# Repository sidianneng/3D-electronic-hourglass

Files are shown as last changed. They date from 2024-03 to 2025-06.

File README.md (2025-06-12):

# 3D 电子沙漏 | [3D Electronic hourglass](./README-EN.md)
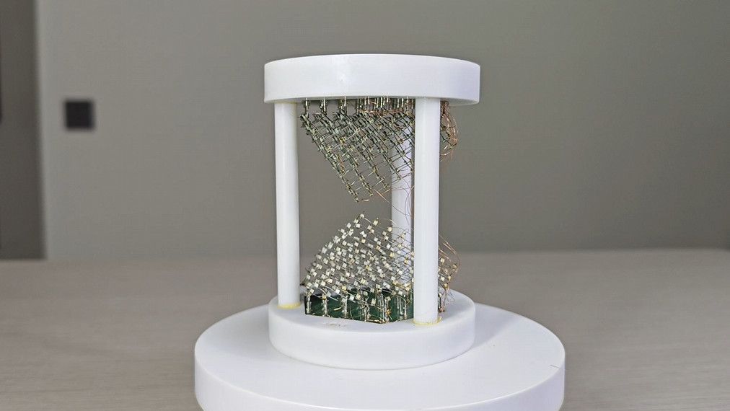
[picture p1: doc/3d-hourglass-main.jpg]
3D Electronic hourglass


## 1 项目概述
本项目是常见的平面电子沙漏的改进版本，在其基础上添加了3D显示结构，匹配对应的显示控制效果，实现了3D立体显示的电子沙漏功能。

## 2 功能介绍
* 开机后随机开始模拟沙漏运行的效果
* 通过陀螺以判断沙漏姿态，来实现不同的运行效果
* 上下各有一个按键，按下后可以切换不同的计时时间(todo)
* 上下各有三个指示灯，用来显示当下正在计时的时间(todo)
* 支持电池供电和充电

## 3 原理解析
* 本项目通过对传统888光立方的创新改装实现
* 通过旋转和剪切立方体，得到与沙漏相似的外观结构
* 通过与平面电子沙漏类似的控制方法实现沙子的流动效果 

### 如果对本项目有任何疑问，欢迎在issue中与我讨论。

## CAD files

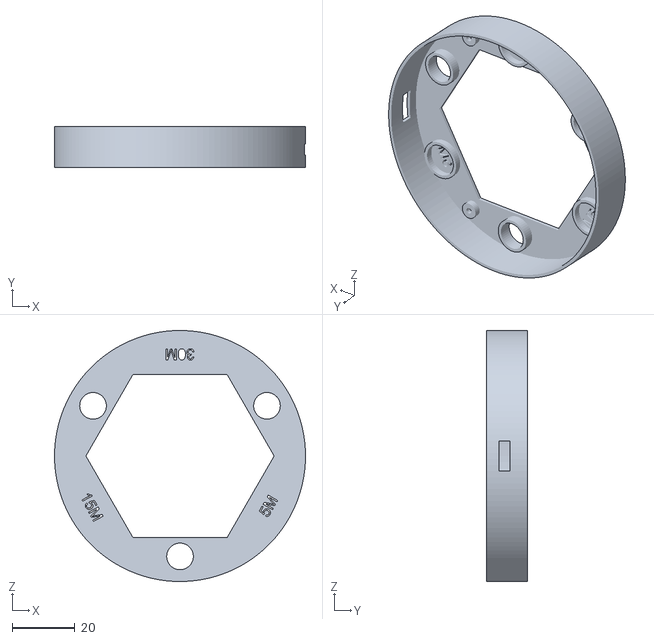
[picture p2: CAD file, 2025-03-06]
3d-modules/bottom-main-v2.stl
80.0 x 13.0 x 80.0

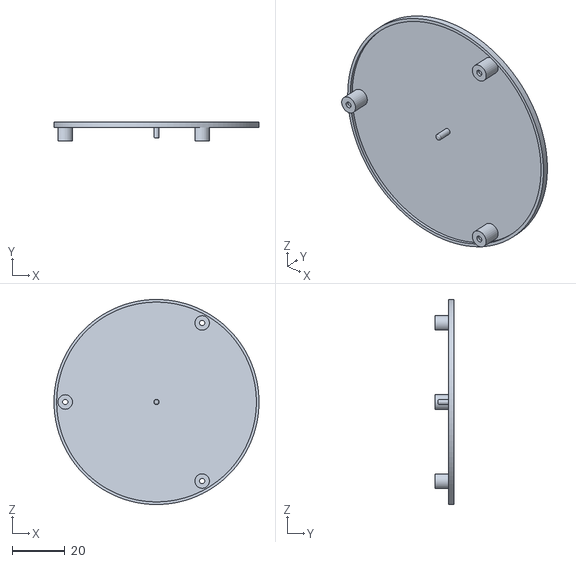
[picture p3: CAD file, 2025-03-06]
3d-modules/bottom-main2-v7.stl
77.5 x 7.00 x 77.5

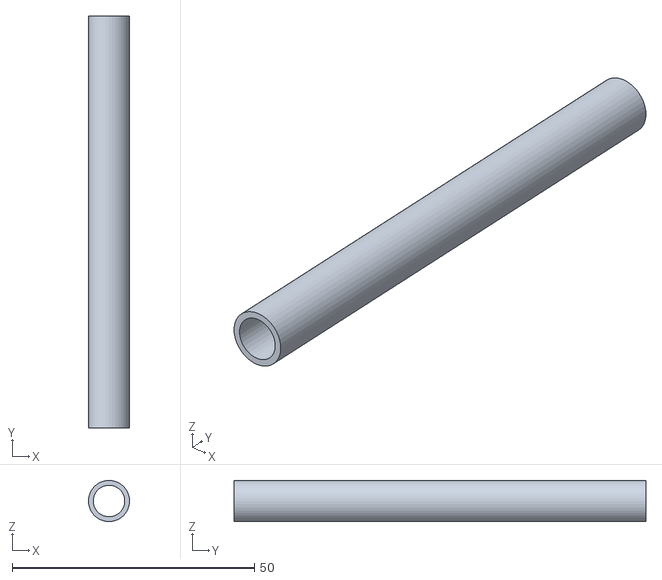
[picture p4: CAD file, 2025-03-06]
3d-modules/hourglass-pillar-v3.stl
8.50 x 85.0 x 8.50

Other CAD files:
3d-modules/top-main-v2.stl

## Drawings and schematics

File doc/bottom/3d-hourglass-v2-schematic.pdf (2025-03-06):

5

4

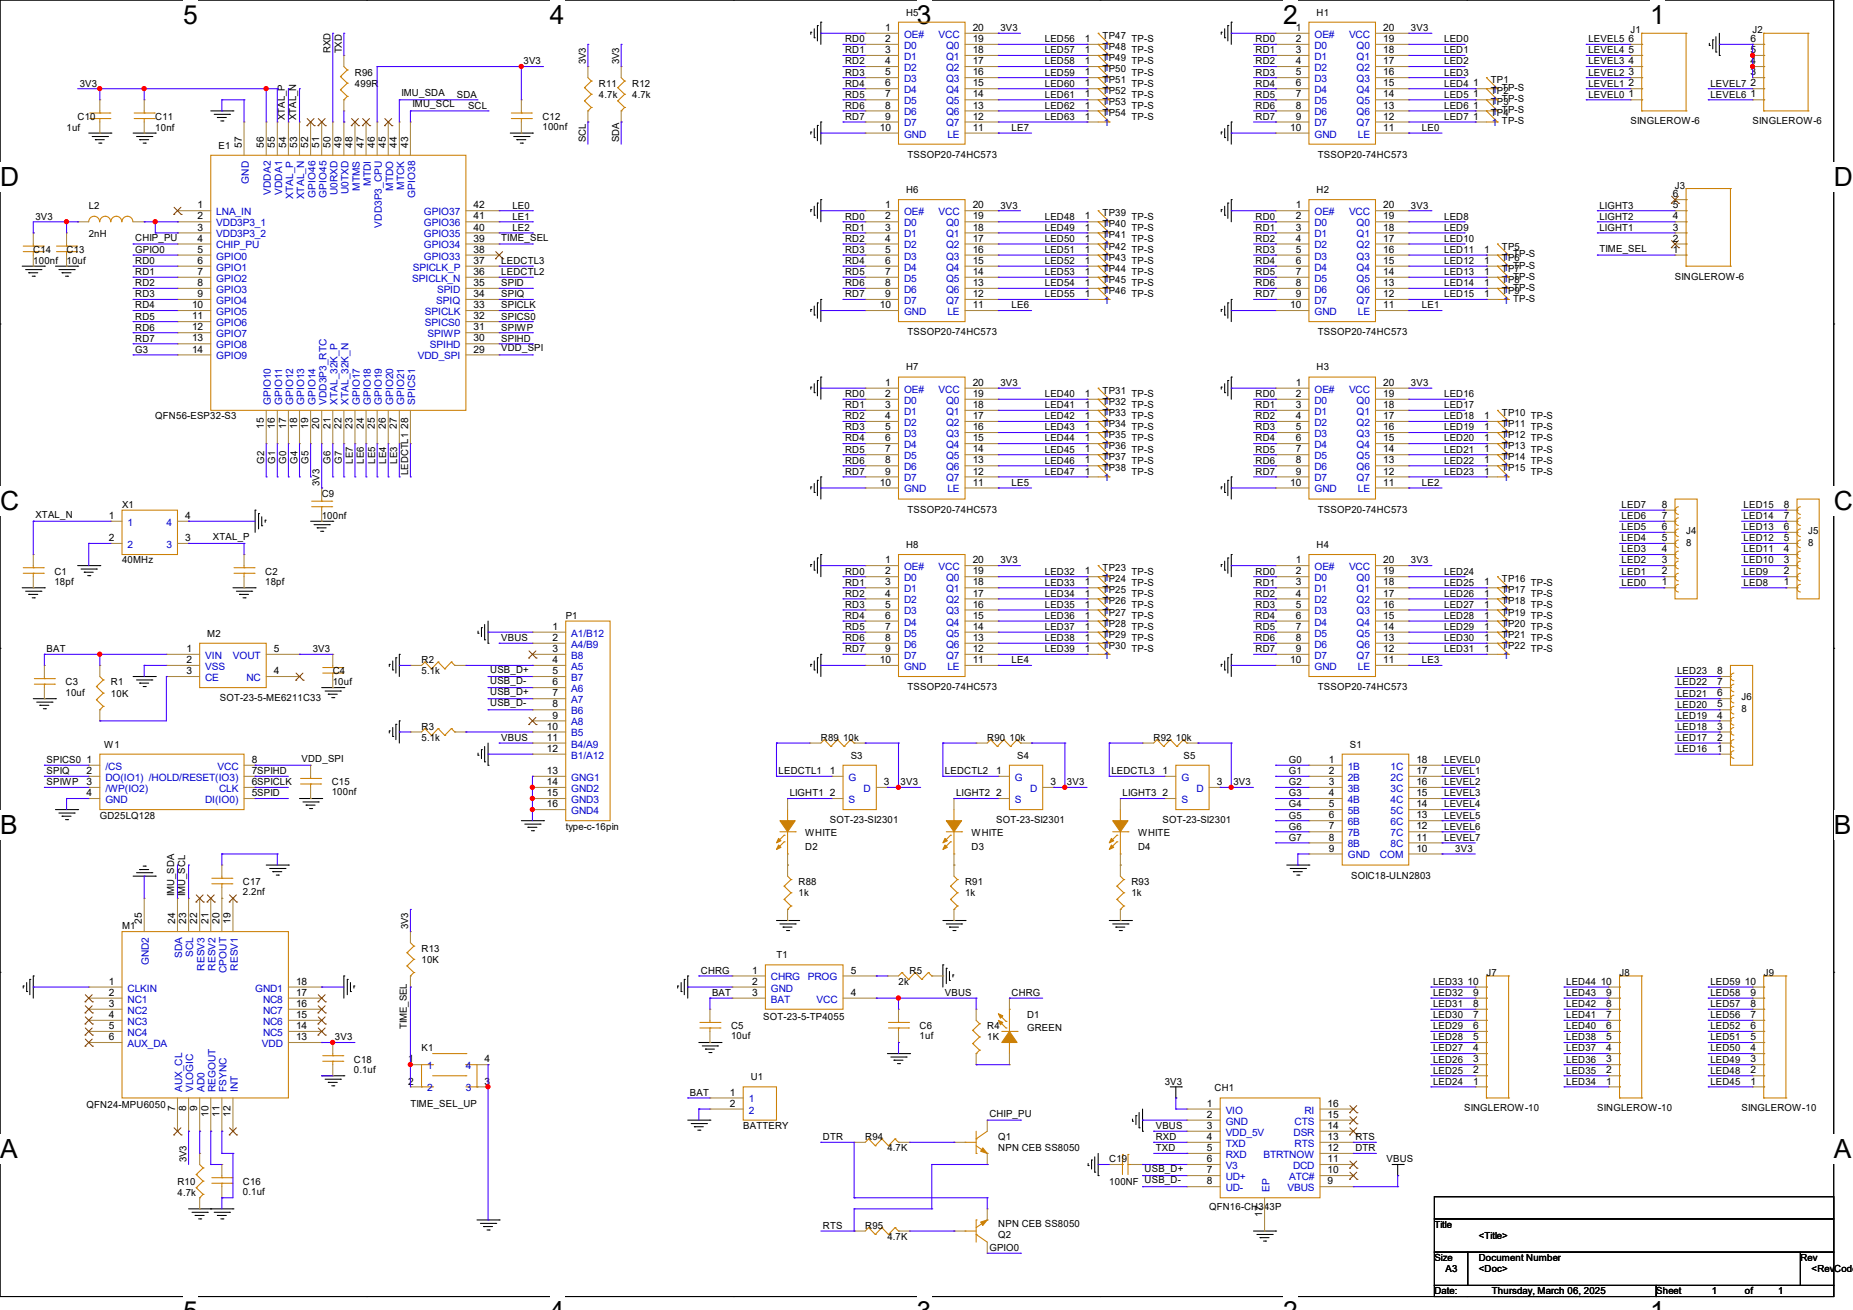
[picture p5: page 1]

9 REGOUT 10 FSYNC 11 INT 12 VDD 13 NC5 14 NC6 15 NC7 16 NC8 17 GND1 18 RESV1 19 CPOUT 20 RESV2 21 RESV3 22 SCL 23 SDA 24 GND2 25

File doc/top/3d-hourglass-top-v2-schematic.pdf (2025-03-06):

5

4

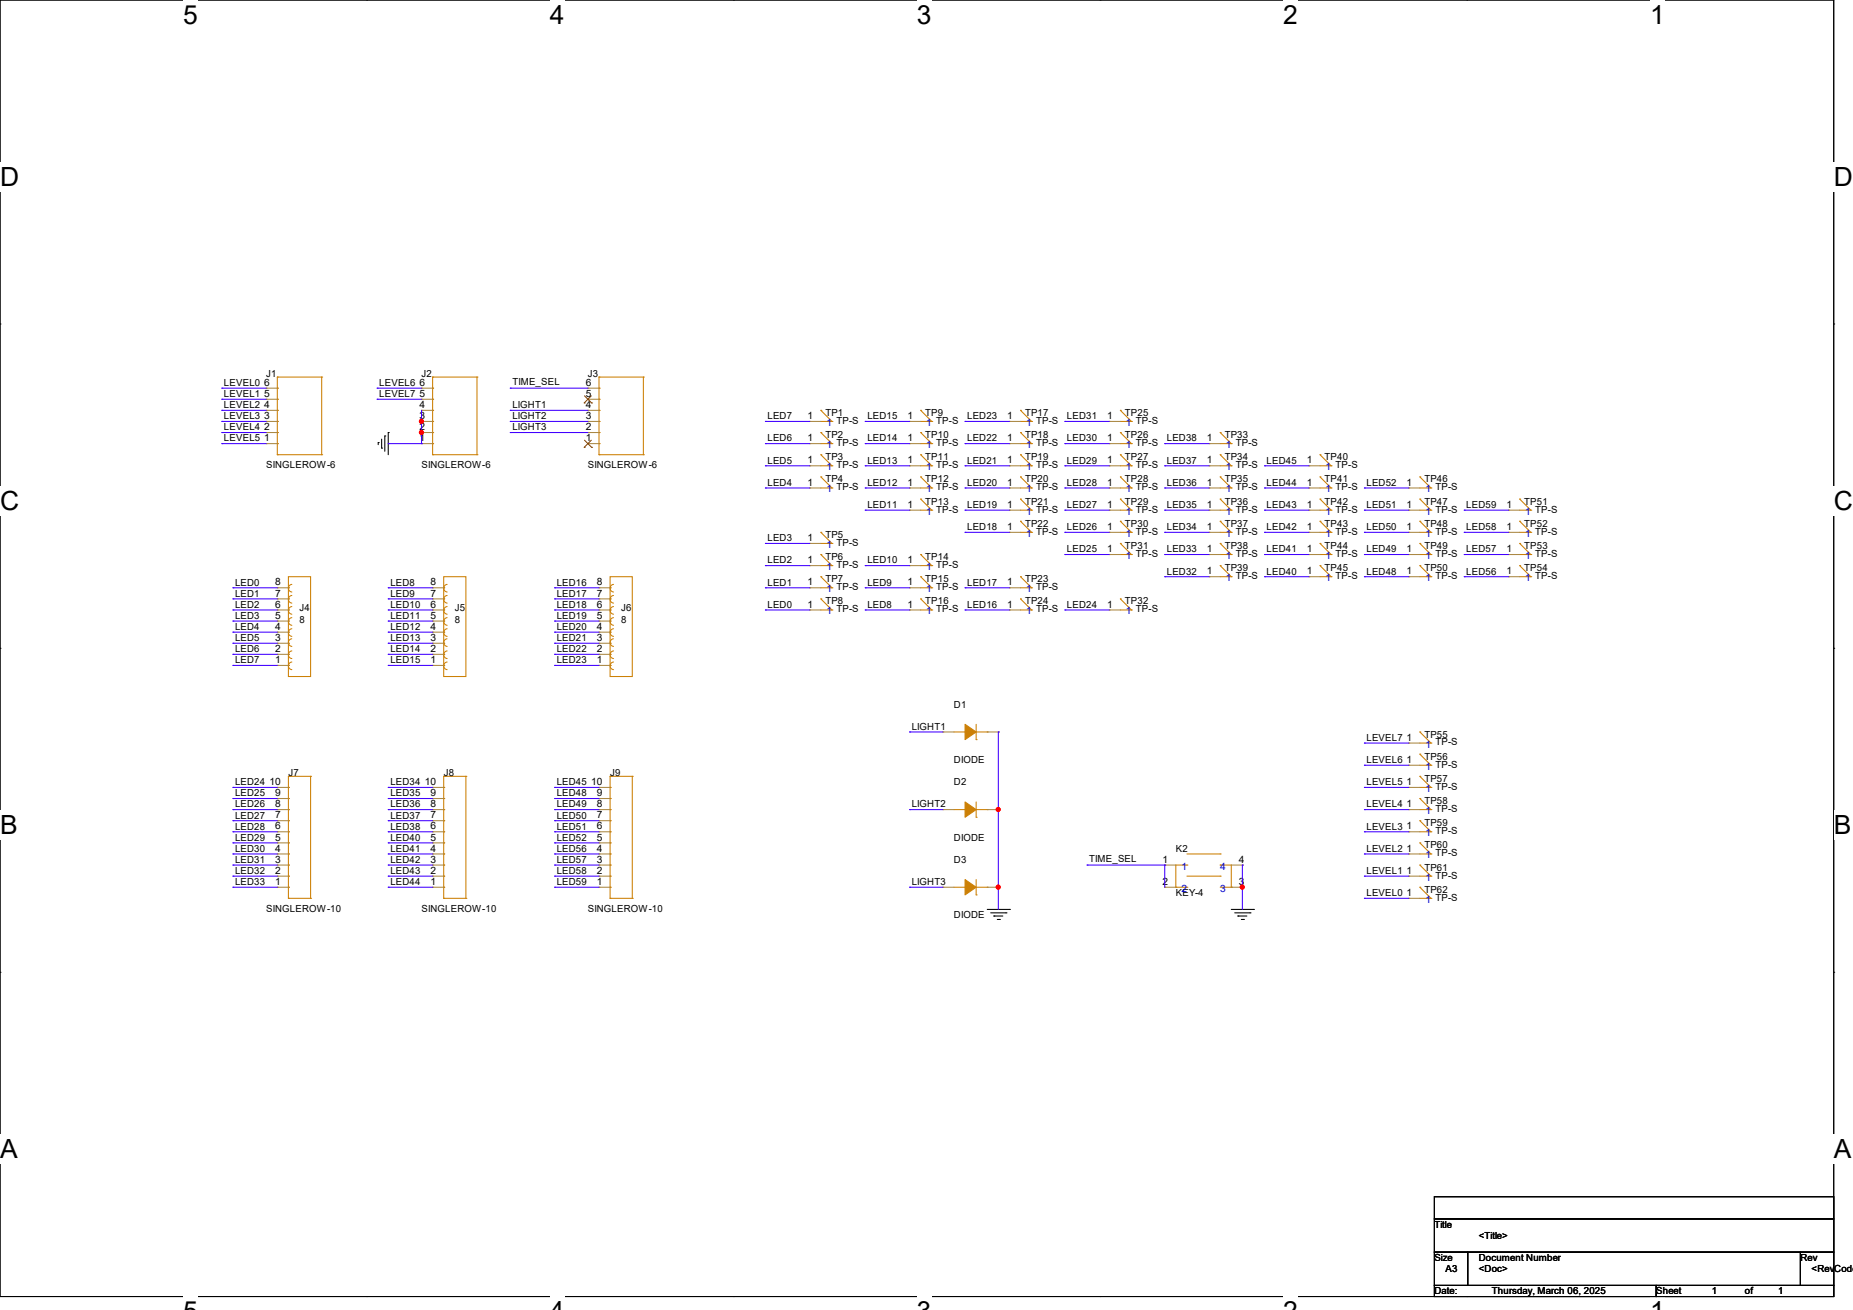
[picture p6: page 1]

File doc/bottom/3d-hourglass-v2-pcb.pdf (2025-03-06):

# TP22 J5

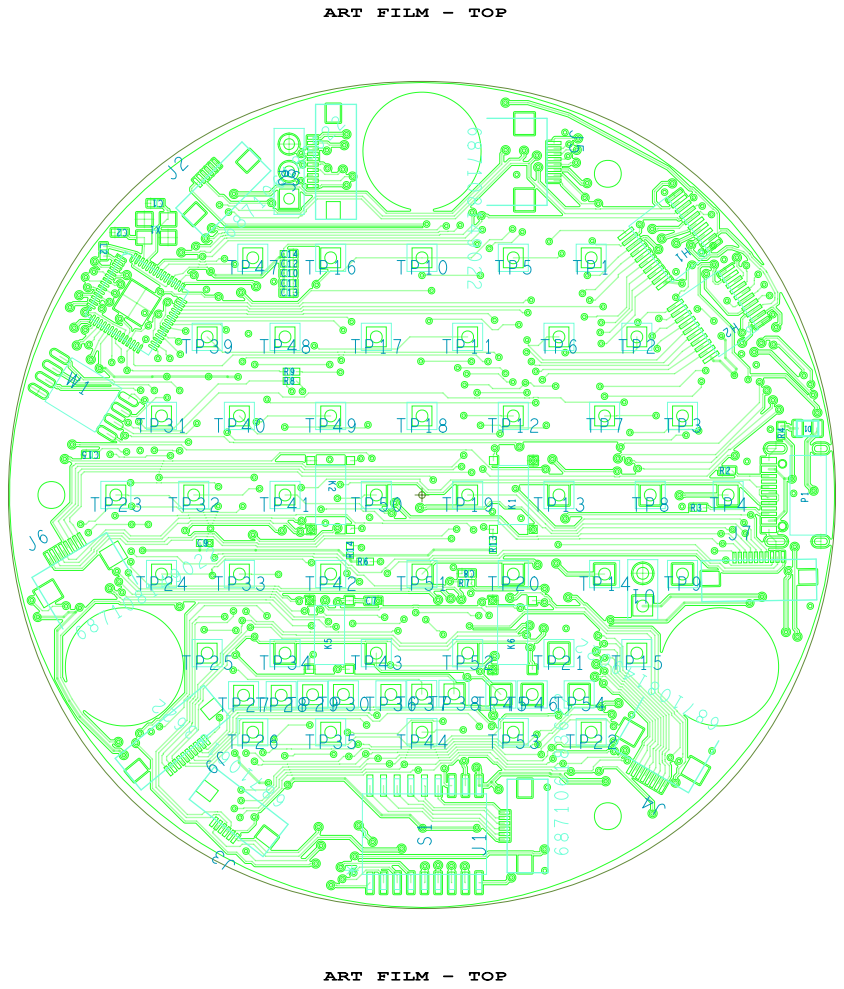
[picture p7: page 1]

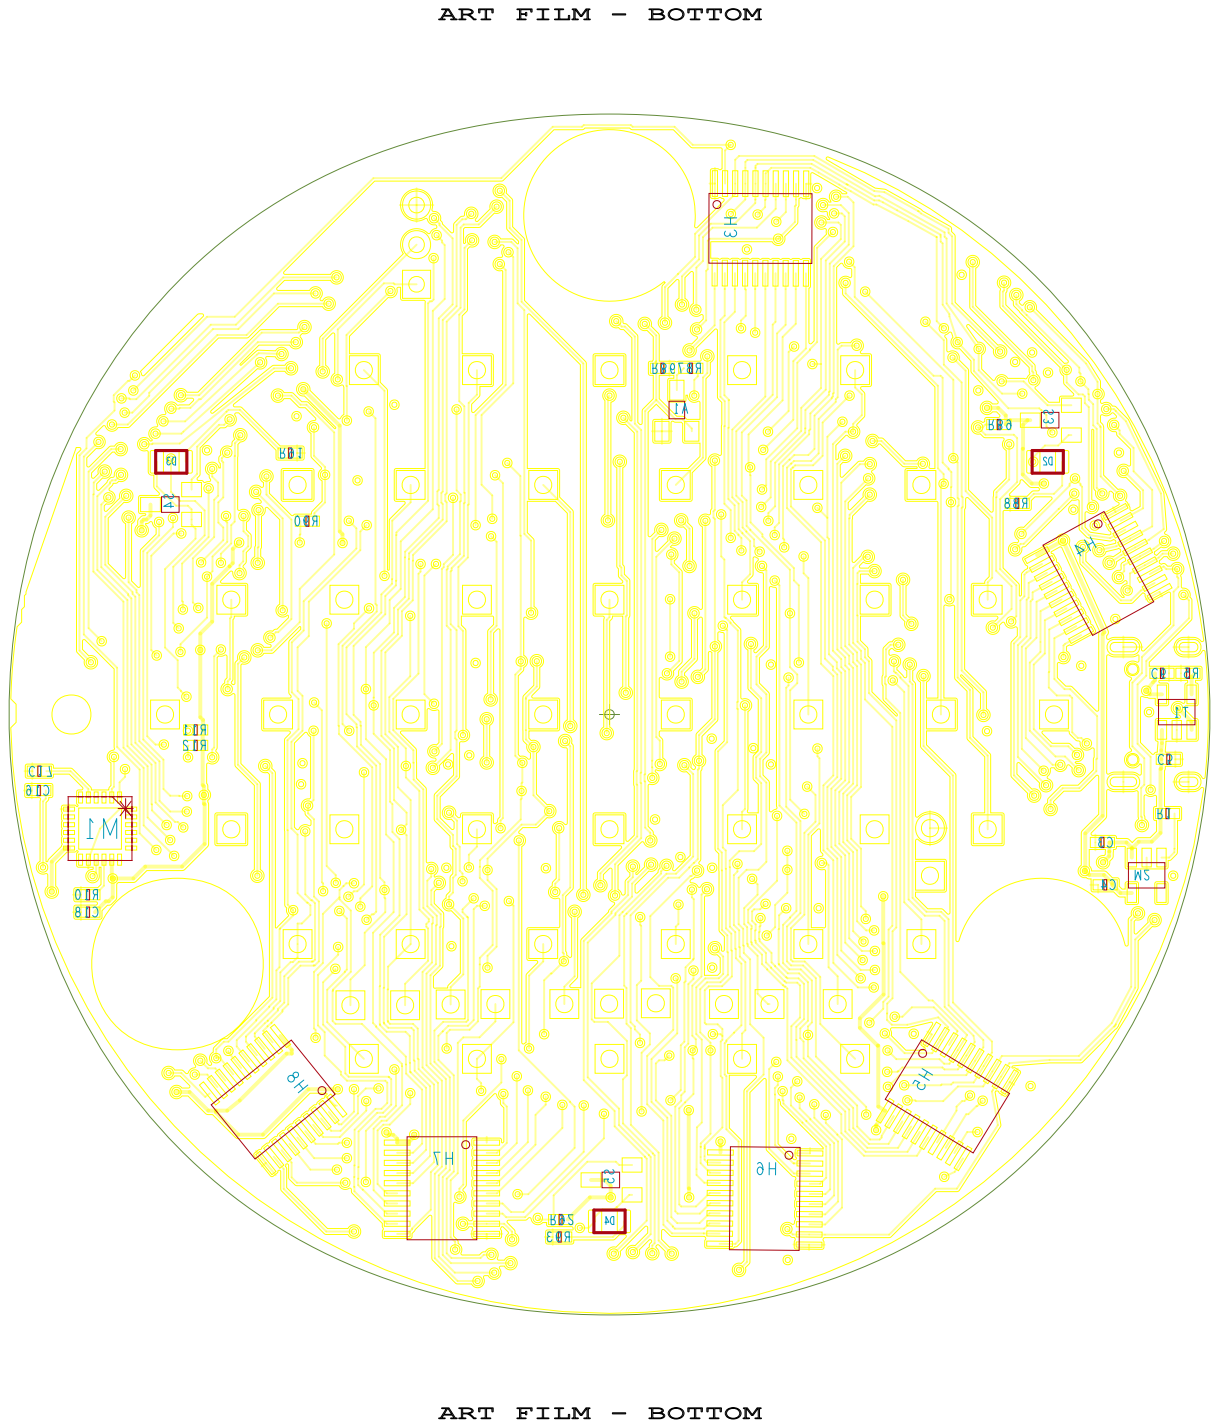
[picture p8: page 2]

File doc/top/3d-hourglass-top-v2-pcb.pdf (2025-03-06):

# TP25J5

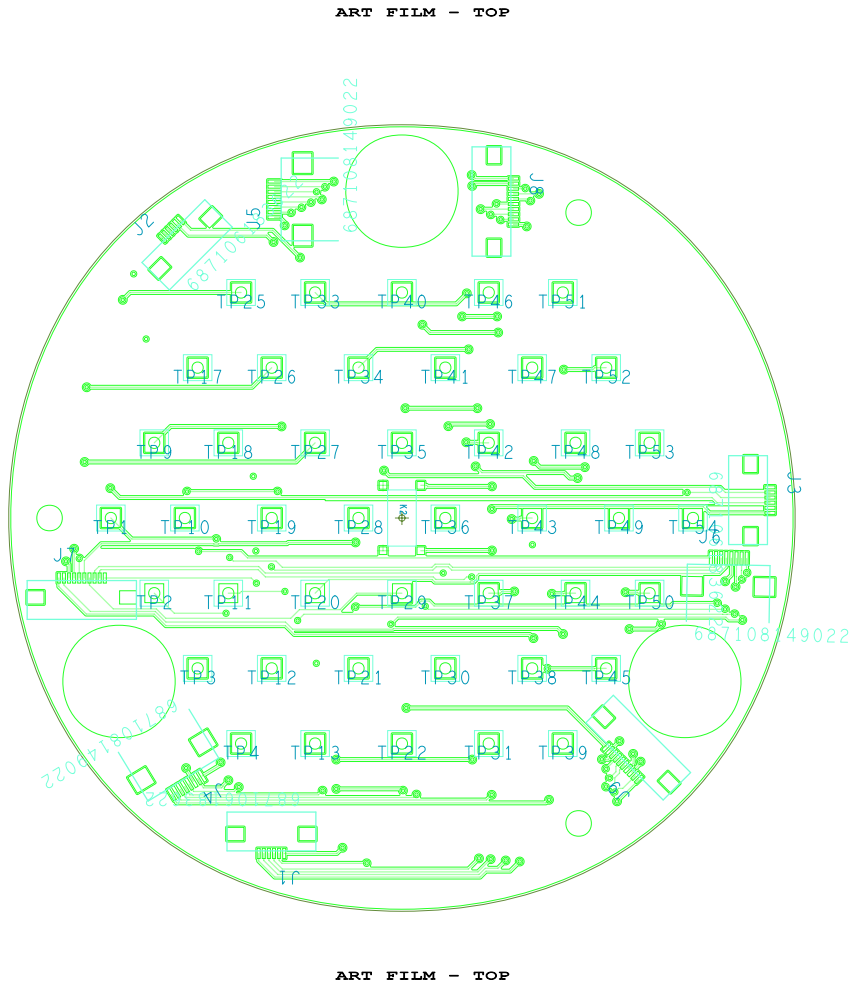
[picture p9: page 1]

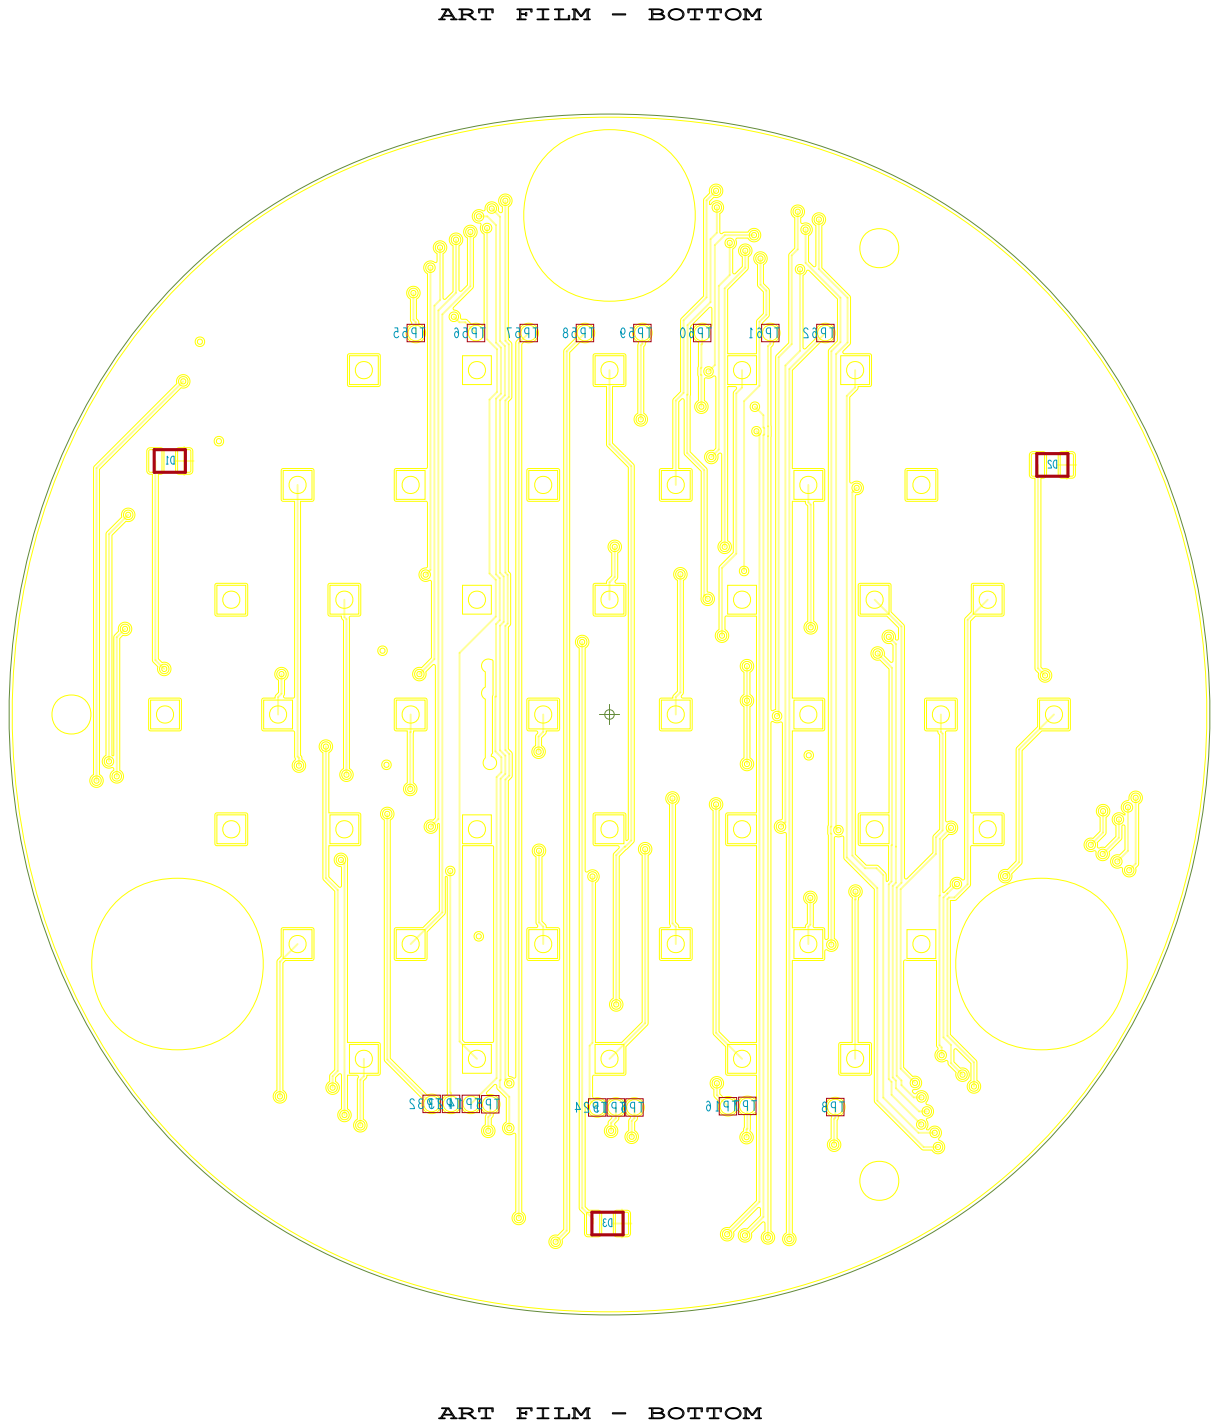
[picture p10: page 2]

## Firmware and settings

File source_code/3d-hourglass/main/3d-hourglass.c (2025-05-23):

#include <stdio.h>
#include "freertos/FreeRTOS.h"
#include "freertos/task.h"
#include "freertos/queue.h"
#include "freertos/FreeRTOSConfig.h"
#include "driver/gpio.h"
#include "ledcube_dis_ctl.h"
#include "hourglass.h"
#include "driver/i2c.h"
#include "parameter.h"
#include <math.h>
#include "driver/mcpwm_prelude.h"
#include "esp_log.h"

//active low
int rd_gpios[8] = {
    CONFIG_GPIO_RD_0,
    CONFIG_GPIO_RD_1,
    CONFIG_GPIO_RD_2,
    CONFIG_GPIO_RD_3,
    CONFIG_GPIO_RD_4,
    CONFIG_GPIO_RD_5,
    CONFIG_GPIO_RD_6,
    CONFIG_GPIO_RD_7,
};

//active low
int g_gpios[8] = {
    CONFIG_GPIO_G_7,
    CONFIG_GPIO_G_6,
    CONFIG_GPIO_G_5,
    CONFIG_GPIO_G_4,
    CONFIG_GPIO_G_3,
    CONFIG_GPIO_G_2,
    CONFIG_GPIO_G_1,
    CONFIG_GPIO_G_0,
};

//active high
int l_gpios[8] = {
    CONFIG_GPIO_L_0,
    CONFIG_GPIO_L_1,
    CONFIG_GPIO_L_2,
    CONFIG_GPIO_L_3,
    CONFIG_GPIO_L_4,
    CONFIG_GPIO_L_5,
    CONFIG_GPIO_L_6,
    CONFIG_GPIO_L_7,
};

static uint8_t ledcube_data[64] = {0x0};

extern float ypr[3];

#define LED_CTRL1 26
#define LED_CTRL2 48
#define LED_CTRL3 47

static const char *TAG = "3d-hourglass";

static void led_cube_display(void* arg)
{
    static uint8_t data_tmp = 0x00;

    //display ledcube
    for(;;) {
        for(uint8_t level = 0;level < 8; level++) {
	    for(uint8_t line = 0;line < 8; line++) {
	        data_tmp = ledcube_data[level * 8 + line];
	        for(uint8_t bit = 0;bit < 8; bit++) {
	            gpio_set_level((gpio_num_t)rd_gpios[bit], (data_tmp & 0x01));
		    data_tmp = (data_tmp >> 1);
                }
	        gpio_set_level((gpio_num_t)l_gpios[line], 1);
	        gpio_set_level((gpio_num_t)l_gpios[line], 0);
	    }
	    for(uint8_t temp = 0;temp < 8; temp++) {
	        if(temp == level)
	            gpio_set_level((gpio_num_t)g_gpios[temp], 1);
	        else
	            gpio_set_level((gpio_num_t)g_gpios[temp], 0);
	    }
	    vTaskDelay(2 / portTICK_PERIOD_MS);
        }
    }
}

void start_i2c(void) {
	i2c_config_t conf;
	conf.mode = I2C_MODE_MASTER;
	conf.sda_io_num = (gpio_num_t)CONFIG_GPIO_SDA;
	conf.scl_io_num = (gpio_num_t)CONFIG_GPIO_SCL;
	conf.sda_pullup_en = GPIO_PULLUP_ENABLE;
	conf.scl_pullup_en = GPIO_PULLUP_ENABLE;
	conf.master.clk_speed = 400000;
	conf.clk_flags = 0;
	ESP_ERROR_CHECK(i2c_param_config(I2C_NUM_0, &conf));
	ESP_ERROR_CHECK(i2c_driver_install(I2C_NUM_0, I2C_MODE_MASTER, 0, 0, 0));
}

void app_main(void)
{
    //zero-initialize the config structure.
    gpio_config_t io_conf = {};
    //disable interrupt
    io_conf.intr_type = GPIO_INTR_DISABLE;
    //set as output mode
    io_conf.mode = GPIO_MODE_OUTPUT;
    //bit mask of the pins that you want to set,e.g.GPIO18/19
    for(uint8_t i = 0;i < 8; ++i)
        io_conf.pin_bit_mask |= ((1ULL << rd_gpios[i]) | (1ULL << g_gpios[i]) | (1ULL << l_gpios[i]));
    //init led control gpio
    io_conf.pin_bit_mask |= ((1ULL << LED_CTRL1) | (1ULL << LED_CTRL2) | (1ULL << LED_CTRL3));
    //disable pull-down mode
    io_conf.pull_down_en = (gpio_pulldown_t)0;
    //disable pull-up mode
    io_conf.pull_up_en = (gpio_pullup_t)0;
    //configure GPIO with the given settings
    gpio_config(&io_conf);

    //Close leds by default
    gpio_set_level(LED_CTRL1, 0);
    gpio_set_level(LED_CTRL2, 0);
    gpio_set_level(LED_CTRL3, 0);

    //Init i2c
    start_i2c();

    int cnt = 0;
    int8_t led_state = 0;
    cube_Init(ledcube_data, sizeof(ledcube_data));

    //close all the leds
    for(uint8_t i = 0;i < 8; ++i) {
	gpio_set_level((gpio_num_t)g_gpios[i], 1);
        gpio_set_level((gpio_num_t)rd_gpios[i], 1);
    }
    for(uint8_t i = 0;i < 8; ++i) {
        gpio_set_level((gpio_num_t)l_gpios[i], 1);
    }

    //create the task for LED display 
    xTaskCreate(led_cube_display, "led_cube_display", 2048, NULL, 10, NULL);

    //create the task for IMU
    xTaskCreate(mpu6050, "IMU", 1024*8, NULL, 10, NULL);

    //plane equation x+y+z=10 for hourglass top
    int8_t h, i, j, k;
    //for(h = -3;h >= -13; h--){
    //    for(i = -1;i >= -8; i--) {
    //        for(j = -1;j >= -8; j--) {
    //            for(k = -1;k >= -8; k--) {
    //        	if(i + j + k == h)
    //        	    cube_SetXYZ(i, j, k, 1);
    //            }
    //        }
    //    }
    //}
    for(h = 0;h <= 10; h++){
        for(i = 0;i < 8; i++) {
            for(j = 0;j < 8; j++) {
                for(k = 0;k < 8; k++) {
            	if(i + j + k == h)
            	    cube_SetXYZ(i, j, k, 1);
                }
            }
        }
    }
    vTaskDelay(1000 / portTICK_PERIOD_MS);

    float yaw;
    int16_t top_sand_num = 0, bottom_sand_num = 0;
#define UP2DOWN 0
#define DOWN2UP 1
#define FALLDOWN 2
    uint8_t previous_orient = UP2DOWN;
    uint8_t current_orient = UP2DOWN;
    uint16_t top_led_num = 0, bottom_led_num = 0;
    uint8_t trigger_led_state = 0;
    while(1) {
	vTaskDelay(100 / portTICK_PERIOD_MS);
	yaw = ypr[0] * RAD_TO_DEG;
	printf("yaw:%f\n", yaw);
	if (yaw <= 45.0 && yaw >= -45.0) { //up to down
		current_orient = UP2DOWN;
		trigger_led_state = 0;
	} else if((yaw >= 135 && yaw <= 180) || (yaw <= -135 && yaw >= -180)) {//down to up
		current_orient = DOWN2UP;
		trigger_led_state = 1;
	} else {//fall down
		current_orient = FALLDOWN;
	}

	//we need to redraw the hourglass
	if((current_orient == UP2DOWN || current_orient == DOWN2UP) && current_orient != previous_orient) {
        	for(i = -8;i <= -1; i++)
        	    for(j = -8;j <= -1; j++)
        	        for(k = -8;k <= -1; k++)
        	            if(i + j + k >= -13)
        	                    bottom_sand_num += cube_GetXYZ(i, j, k);
		top_sand_num = 256 - bottom_sand_num;

		//close all the leds
        	for(uint8_t i = 0;i < 8; i++)
        	    for(uint8_t j = 0;j < 8; j++)
        	        for(uint8_t k = 0;k < 8; k++) 
        	    	    cube_SetXYZ(i, j, k, 0);

		if(current_orient == DOWN2UP) {
			//draw the down part
    			for(h = -3;h >= -13; h--) {
    			    for(i = -1;i >= -8; i--) {
    			        for(j = -1;j >= -8; j--) {
    			            for(k = -1;k >= -8; k--) {
    			                if(i + j + k == h) {
    			                    cube_SetXYZ(i, j, k, 1);
					    bottom_led_num++;
					    if(bottom_led_num >= bottom_sand_num) {
					        bottom_led_num = 0;
						goto down_draw_finish1; 
					    }
					}
    			            }
    			        }
    			    }
    			}
down_draw_finish1:
			//draw the top part
			for(h = 10;h >= 0; h--){
			    for(i = 0;i <= 7; i++) {
			        for(j = 0;j <= 7; j++) {
			            for(k = 0;k <= 7; k++) {
			                if(i + j + k == h) {
			                    cube_SetXYZ(i, j, k, 1);
					    top_led_num++;
					    if(top_led_num >= top_sand_num) {
					        top_led_num = 0;
						goto top_draw_finish1;
					    }
				        }
			            }
			        }
			    }
			}
top_draw_finish1:
		} else { //current_orient == UP2DOWN
			//draw the down part
    			for(h = -13;h <= -3; h++) {
    			    for(i = -1;i >= -8; i--) {
    			        for(j = -1;j >= -8; j--) {
    			            for(k = -1;k >= -8; k--) {
    			                if(i + j + k == h) {
    			                    cube_SetXYZ(i, j, k, 1);
					    bottom_led_num++;
					    if(bottom_led_num >= bottom_sand_num) {
					        bottom_led_num = 0;
						goto down_draw_finish2; 
					    }
					}
    			            }
    			        }
    			    }
    			}
down_draw_finish2:
			//draw the top part
			for(h = 0;h <= 10; h++){
			    for(i = 0;i <= 7; i++) {
			        for(j = 0;j <= 7; j++) {
			            for(k = 0;k <= 7; k++) {
			                if(i + j + k == h) {
			                    cube_SetXYZ(i, j, k, 1);
					    top_led_num++;
					    if(top_led_num >= top_sand_num) {
					        top_led_num = 0;
						goto top_draw_finish2;
					    }
				        }
			            }
			        }
			    }
			}
top_draw_finish2:
		}
	}

	if(current_orient == UP2DOWN) {
            for(i = 0;i <= 7; i++)
	        for(j = 0;j <= 7; j++)	
	    	    for(k = 0;k <= 7; k++){
	                if(i + j + k <= 10)
	    		hg_MoveSand(HG_TOP, HG_UP, i, j, k);
	    	    }
            for(i = -8;i <= -1; i++)
	        for(j = -8;j <= -1; j++)	
	    	    for(k = -8;k <= -1; k++){
	                if(i + j + k >= -13)
	    		hg_MoveSand(HG_BOTTOM, HG_DOWN, i, j, k);
	    	    }
	} else if(current_orient == DOWN2UP) {
            for(i = 7;i >= 0; i--)
	        for(j = 7;j >= 0; j--)	
	    	    for(k = 7;k >= 0; k--){
	                if(i + j + k <= 10)
	    		hg_MoveSand(HG_TOP, HG_DOWN, i, j, k);
	    	    }
            for(i = -1;i >= -8; i--)
	        for(j = -1;j >= -8; j--)	
	    	    for(k = -1;k >= -8; k--){
	                if(i + j + k >= -13)
	    		hg_MoveSand(HG_BOTTOM, HG_UP, i, j, k);
	    	    }
	}

	printf("cnt:%d\n", cnt++);
	top_sand_num = 0;
	bottom_sand_num = 0;

	if(cnt % 2 == 0) {
	    cube_SetXYZ(0, 0, 0, trigger_led_state);
            cube_SetXYZ(-1, -1, -1, !trigger_led_state);
	}

	//store the current orientation
	previous_orient = current_orient;

    }
}

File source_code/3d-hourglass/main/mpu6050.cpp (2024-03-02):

// I2C device class (I2Cdev) demonstration Arduino sketch for MPU6050 class using DMP (MotionApps v2.0)
// 6/21/2012 by Jeff Rowberg <jeff@rowberg.net>
// Updates should (hopefully) always be available at https://github.com/jrowberg/i2cdevlib
//
// Changelog:
//		2023-03-10 - Fit to esp-idf v5
//		2019-07-08 - Added Auto Calibration and offset generator
//		   - and altered FIFO retrieval sequence to avoid using blocking code
//		2016-04-18 - Eliminated a potential infinite loop
//		2013-05-08 - added seamless Fastwire support
//				   - added note about gyro calibration
//		2012-06-21 - added note about Arduino 1.0.1 + Leonardo compatibility error
//		2012-06-20 - improved FIFO overflow handling and simplified read process
//		2012-06-19 - completely rearranged DMP initialization code and simplification
//		2012-06-13 - pull gyro and accel data from FIFO packet instead of reading directly
//		2012-06-09 - fix broken FIFO read sequence and change interrupt detection to RISING
//		2012-06-05 - add gravity-compensated initial reference frame acceleration output
//				   - add 3D math helper file to DMP6 example sketch
//				   - add Euler output and Yaw/Pitch/Roll output formats
//		2012-06-04 - remove accel offset clearing for better results (thanks Sungon Lee)
//		2012-06-01 - fixed gyro sensitivity to be 2000 deg/sec instead of 250
//		2012-05-30 - basic DMP initialization working

/* ============================================
I2Cdev device library code is placed under the MIT license
Copyright (c) 2012 Jeff Rowberg
Permission is hereby granted, free of charge, to any person obtaining a copy
of this software and associated documentation files (the "Software"), to deal
in the Software without restriction, including without limitation the rights
to use, copy, modify, merge, publish, distribute, sublicense, and/or sell
copies of the Software, and to permit persons to whom the Software is
furnished to do so, subject to the following conditions:
The above copyright notice and this permission notice shall be included in
all copies or substantial portions of the Software.
THE SOFTWARE IS PROVIDED "AS IS", WITHOUT WARRANTY OF ANY KIND, EXPRESS OR
IMPLIED, INCLUDING BUT NOT LIMITED TO THE WARRANTIES OF MERCHANTABILITY,
FITNESS FOR A PARTICULAR PURPOSE AND NONINFRINGEMENT. IN NO EVENT SHALL THE
AUTHORS OR COPYRIGHT HOLDERS BE LIABLE FOR ANY CLAIM, DAMAGES OR OTHER
LIABILITY, WHETHER IN AN ACTION OF CONTRACT, TORT OR OTHERWISE, ARISING FROM,
OUT OF OR IN CONNECTION WITH THE SOFTWARE OR THE USE OR OTHER DEALINGS IN
THE SOFTWARE.
===============================================
*/

#include "freertos/FreeRTOS.h"
#include "freertos/task.h"
#include "freertos/queue.h"
#include "freertos/message_buffer.h"
#include "esp_log.h"
#include "esp_err.h"
#include "driver/i2c.h"

#include "parameter.h"

extern QueueHandle_t xQueueTrans;
extern MessageBufferHandle_t xMessageBufferToClient;

static const char *TAG = "IMU";

// I2Cdev and MPU6050 must be installed as libraries, or else the .cpp/.h files
// for both classes must be in the include path of your project
#include "I2Cdev.h"

//#include "MPU6050.h" // not necessary if using MotionApps include file
#include "MPU6050_6Axis_MotionApps20.h"

MPU6050 mpu;

// MPU control/status vars
bool dmpReady = false;	// set true if DMP init was successful
uint8_t mpuIntStatus;	// holds actual interrupt status byte from MPU
uint8_t devStatus;		// return status after each device operation (0 = success, !0 = error)
uint16_t packetSize;	// expected DMP packet size (default is 42 bytes)
uint16_t fifoCount;		// count of all bytes currently in FIFO
uint8_t fifoBuffer[64]; // FIFO storage buffer

// orientation/motion vars
Quaternion q;			// [w, x, y, z]			quaternion container
VectorInt16 aa;			// [x, y, z]			accel sensor measurements
VectorInt16 aaReal;		// [x, y, z]			gravity-free accel sensor measurements
VectorInt16 aaWorld;	// [x, y, z]			world-frame accel sensor measurements
VectorFloat gravity;	// [x, y, z]			gravity vector
float euler[3];			// [psi, theta, phi]	Euler angle container
float ypr[3];			// [yaw, pitch, roll]	yaw/pitch/roll container and gravity vector

// packet structure for InvenSense teapot demo
uint8_t teapotPacket[14] = { '$', 0x02, 0,0, 0,0, 0,0, 0,0, 0x00, 0x00, '\r', '\n' };

// display quaternion values in easy matrix form: w x y z
void getQuaternion() {
	mpu.dmpGetQuaternion(&q, fifoBuffer);
	printf("quat x:%6.2f y:%6.2f z:%6.2f w:%6.2f\n", q.x, q.y, q.z, q.w);
}

// display Euler angles in degrees
void getEuler() {
	mpu.dmpGetQuaternion(&q, fifoBuffer);
	mpu.dmpGetEuler(euler, &q);
	printf("euler psi:%6.2f theta:%6.2f phi:%6.2f\n", euler[0] * RAD_TO_DEG, euler[1] * RAD_TO_DEG, euler[2] * RAD_TO_DEG);
}

// display Euler angles in degrees
void getYawPitchRoll() {
	mpu.dmpGetQuaternion(&q, fifoBuffer);
	mpu.dmpGetGravity(&gravity, &q);
	mpu.dmpGetYawPitchRoll(ypr, &q, &gravity);
#if 0
	float _roll = ypr[2] * RAD_TO_DEG;
	float _pitch = ypr[1] * RAD_TO_DEG;
	float _yaw = ypr[0] * RAD_TO_DEG;
	ESP_LOGI(TAG, "roll:%f pitch:%f yaw:%f",_roll, _pitch, _yaw);
#endif
	//printf("ypr roll:%3.1f pitch:%3.1f yaw:%3.1f\n",ypr[2] * RAD_TO_DEG, ypr[1] * RAD_TO_DEG, ypr[0] * RAD_TO_DEG);
	//ESP_LOGI(TAG, "roll:%f pitch:%f yaw:%f",ypr[2] * RAD_TO_DEG, ypr[1] * RAD_TO_DEG, ypr[0] * RAD_TO_DEG);
}

// display real acceleration, adjusted to remove gravity
void getRealAccel() {
	mpu.dmpGetQuaternion(&q, fifoBuffer);
	mpu.dmpGetAccel(&aa, fifoBuffer);
	mpu.dmpGetGravity(&gravity, &q);
	mpu.dmpGetLinearAccel(&aaReal, &aa, &gravity);
	printf("areal x=%d y:%d z:%d\n", aaReal.x, aaReal.y, aaReal.z);
}

// display initial world-frame acceleration, adjusted to remove gravity
// and rotated based on known orientation from quaternion
void getWorldAccel() {
	mpu.dmpGetQuaternion(&q, fifoBuffer);
	mpu.dmpGetAccel(&aa, fifoBuffer);
	mpu.dmpGetGravity(&gravity, &q);
	mpu.dmpGetLinearAccel(&aaReal, &aa, &gravity);
	mpu.dmpGetLinearAccelInWorld(&aaWorld, &aaReal, &q);
	printf("aworld x:%d y:%d z:%d\n", aaWorld.x, aaWorld.y, aaWorld.z);
}
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

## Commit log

2024-01-09 light up the led cube
2024-01-10 create task for led cude display
2024-01-12 add led cube display control API
2024-01-13 hourglass flow display demo is ok
2024-01-20 add code for IMU(MPU6050 DMP)
2024-01-22 IMU dynamic control led matrix OK
2024-02-23 fix the led matrix control with IMU
    [3d-hourglass.c]
2024-03-02 IMU control sand flow OK
2024-03-03 fix hourglass redraw when orientation changed
    [3d-hourglass.c]
2024-03-03 add demo code for pwm
2025-03-06 upload gerber PCB schematic and BOM
2025-03-06 upload 3d modules
    [bottom-main-v2.stl, bottom-main2-v7.stl, hourglass-pillar-v3.stl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]
2025-05-20 update bit control of led display task
2025-05-21 remove the code of pwm
2025-05-22 close time tag leds by default
2025-05-26 add led matrix convert buffer I did this to fix the hardware fault only.It's a hardware design issue.
2025-05-26 finish the led matrix convert buffer
